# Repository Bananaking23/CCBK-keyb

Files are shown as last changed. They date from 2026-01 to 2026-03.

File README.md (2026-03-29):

# CCBK-keyb
I have decided to make this keyboard as I currently have a 68% keyboard and it feels bad not have f keys and home and delete, as I like to code and those keys are useful shortcuts. The switches I chose sound great and are relatively cheap. This project also improved my skills as I have only made a PCB ones (the hackpad). 

This is my berry cool 75% keyboard, it has a display, 80 keys, under-key lights, and a rotary encoder. It is powered by a rp2040 plus and uses an mcu23017 as gpio extender

# Photos

## almost full thing




for some reason i couldnt get all the keycaps on

## Scematic
### Main 


### Switch Matrix


### Led


## pcb

## Case


### Usb-c


### Plate


# BOM


### Link
https://1drv.ms/x/c/3f7de78506c0c654/IQBztQz0UetkR5LsrjEMn85vARuH-ncA3dCGhFmHGj_PK4U?e=rccWr9

#A fter completion

## Case



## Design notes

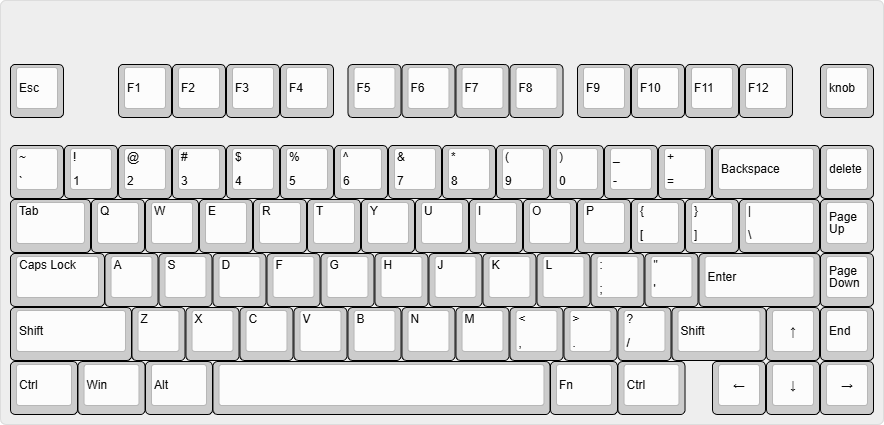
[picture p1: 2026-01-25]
KEYBOARD_DIY/keyboard-layout.png

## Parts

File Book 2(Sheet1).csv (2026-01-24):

name | description | price | amount | total price(GBP) | Total price(usd) | Running price | LINK
rp2040 plus | micrcontroller | 5.99 | 1 |  | 10.99 | 5.99 | https://www.waveshare.com/rp2040-plus.htm?sku=20290
creamy jade | switches | 16.31 | 1 | 16.31 | 22.1816 | 16.98 | https://s.click.aliexpress.com/e/_Ew0y6KC
kalih hotswap plugs | make kb hotwsap | 6.89 | 1 | 6.89 | 9.3704 | 39.1616 | https://s.click.aliexpress.com/e/_Eu0bNPO
MCP23017 | Port expander | 2.01 | 1 | 2.01 | 2.7336 | 48.532 | https://s.click.aliexpress.com/e/_EypYMqC
0.91 inch oled | shows info | 1.79 | 1 | 1.79 | 2.4344 | 51.2656 | https://a.aliexpress.com/_EuIBQWY
stabilizer | for long keys | 3.94 | 1 | 3.94 | 5.3584 | 53.7 | https://s.click.aliexpress.com/e/_ExPudE8
m3 heat inserts | screw things in | 2.46 | 1 | 2.46 | 3.3456 | 59.0584 | https://s.click.aliexpress.com/e/_EJB9bIc
rotary encoder | change things like volume | 0.79 | 1 | 0.79 | 1.0744 | 62.404 | https://s.click.aliexpress.com/e/_EuTjwLi
1n4148w diodes | stop ghosting | 1.25 | 1 | 1.25 | 1.7 | 63.4784 | https://s.click.aliexpress.com/e/_Ey54lbQ
step up converter | change 3.3v to 5v for leds | 0.72 | 1 | 0.72 | 0.9792 | 65.1784 | https://a.aliexpress.com/_ExfFVog
rubber feet | stop keyboard from slipping | 1.22 | 1 | 1.22 | 1.6592 | 66.1576 | https://s.click.aliexpress.com/e/_EHUOXNE
sk6812 mini | lights for keys | 4.69 | 1 | 4.69 | 6.3784 | 67.8168 | https://a.aliexpress.com/_EwElRLO
case | 3d printed-keep everything together | 0 | 1 | 0 | 0 | 67.8168
keycaps | for switches - already owned | 0 | 1 | 0 | 0 | 74.1952
pcb | connect all together | 25.87 | 1 | 0 | 25.87 | 74.1952 | https://jlcpcb.com
 |  |  |  |  |  | 100.0652 | With discounts: | $96

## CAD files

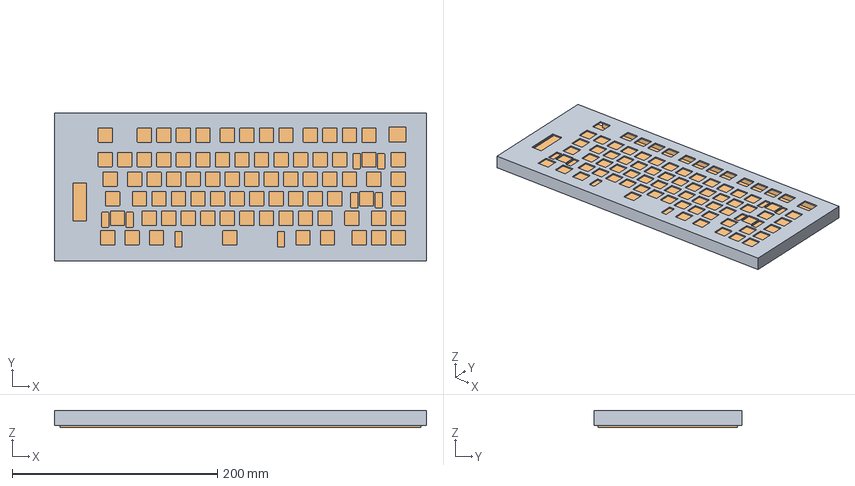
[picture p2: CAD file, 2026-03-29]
KEYBOARD_DIY/CAD/cad finished/complete.step
362.8 x 144.1 x 16.6 mm
PLATE
case

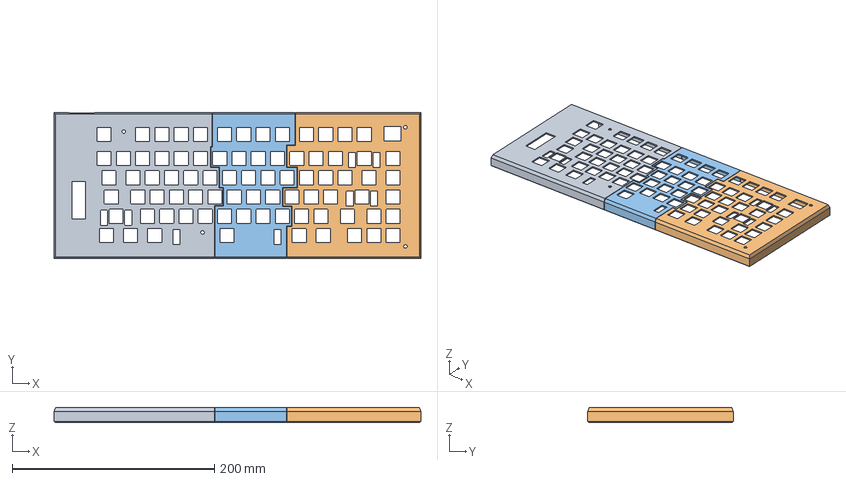
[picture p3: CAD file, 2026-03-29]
KEYBOARD_DIY/CAD/cad finished/PLATE.step
362.8 x 144.1 x 14.5 mm

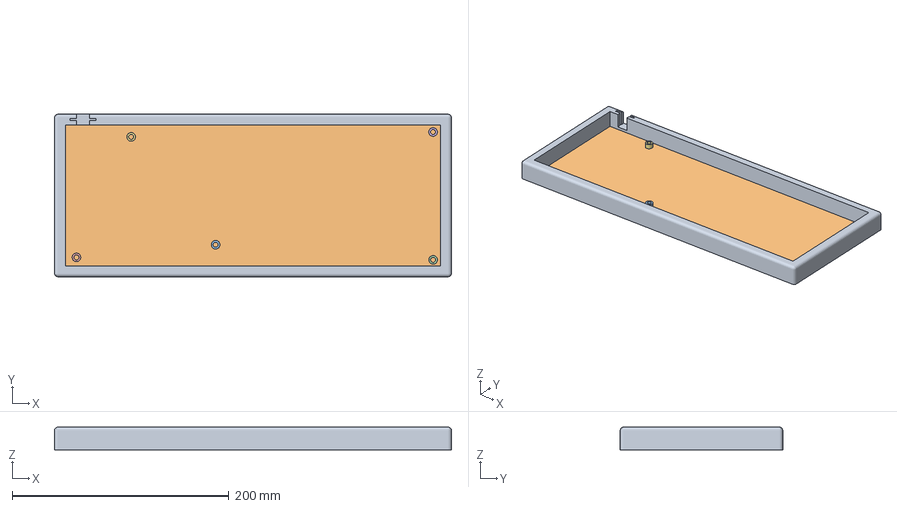
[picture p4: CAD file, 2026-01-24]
KEYBOARD_DIY/CAD/case.3mf
366.2 x 150.0 x 21.1 mm

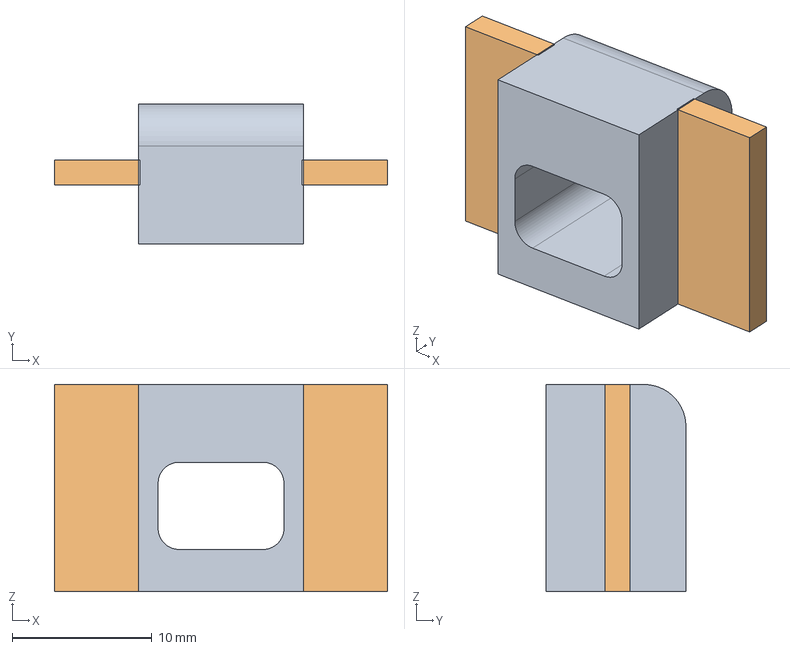
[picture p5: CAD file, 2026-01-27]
KEYBOARD_DIY/CAD/keyboard steps/USB.step
23.8 x 10.0 x 14.8 mm

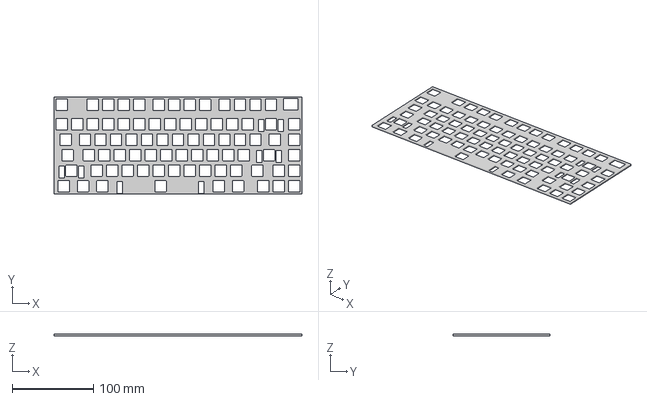
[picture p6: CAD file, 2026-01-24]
KEYBOARD_DIY/CAD/PLATE.3mf
304.8 x 119.1 x 2.00 mm

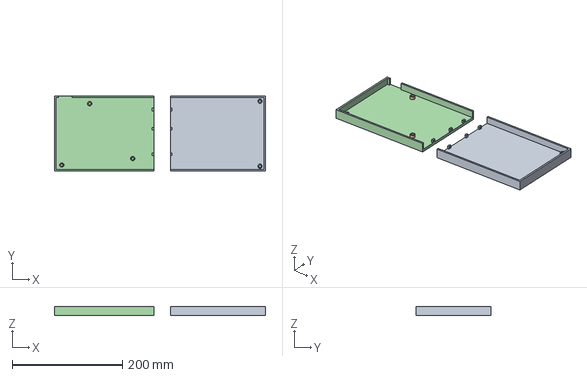
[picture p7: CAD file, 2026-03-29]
KEYBOARD_DIY/CAD/cad finished/case.step
382.2 x 136.0 x 16.1 mm

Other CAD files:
KEYBOARD_DIY/CAD/keyboard steps/case.step
KEYBOARD_DIY/CAD/USB.3mf
KEYBOARD_DIY/CAD/cad finished/PLATE.f3d
KEYBOARD_DIY/CAD/cad finished/case.f3d
KEYBOARD_DIY/CAD/cad finished/complete.f3z

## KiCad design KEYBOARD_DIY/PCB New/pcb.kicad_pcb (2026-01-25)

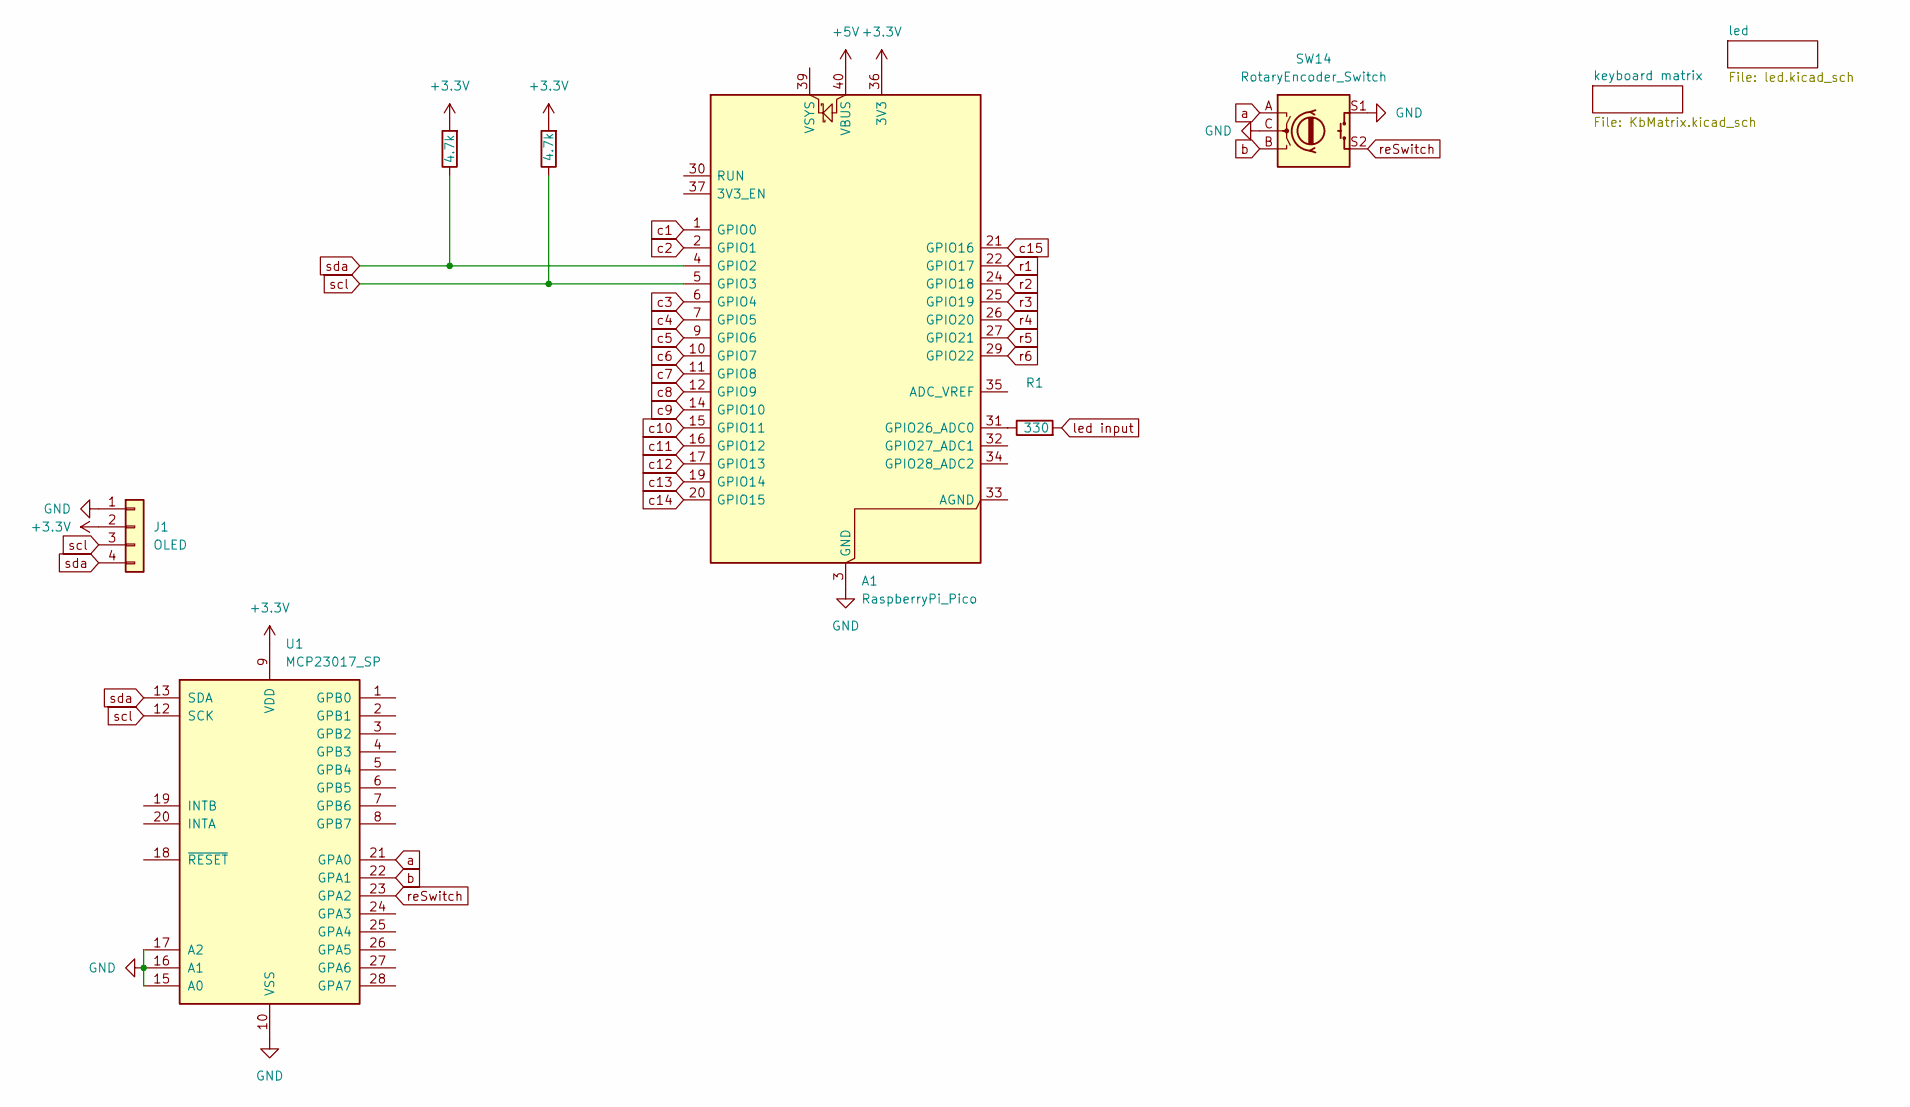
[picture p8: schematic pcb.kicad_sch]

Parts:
A1: RaspberryPi_Pico; RaspberryPi_Pico_Common_Unspecified
J1: OLED; SSD1306-0.91-OLED-4pin-128x32
R1: 330; R_Axial_DIN0207_L6.3mm_D2.5mm_P7.62mm_Horizontal
R2, R3: 4.7k; R_Axial_DIN0207_L6.3mm_D2.5mm_P7.62mm_Horizontal
SW14: RotaryEncoder_Switch; RotaryEncoder_Alps_EC11E-Switch_Vertical_H20mm
U1: MCP23017_SP; DIP-28_W7.62mm

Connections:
+3.3V: A1.36 (3V3), J1.2, R2.2, R3.2, U1.9 (VDD)
+5V: A1.40 (VBUS); also elsewhere on the board
GND: A1.3 (GND), A1.8 (GND), A1.13 (GND), A1.18 (GND), A1.23 (GND), A1.28 (GND), A1.38 (GND), J1.1, SW14.C, SW14.S1, U1.10 (VSS), U1.15 (A0), U1.16 (A1), U1.17 (A2); also elsewhere on the board
unnamed: A1.31 (GPIO26_ADC0), R1.1
a: SW14.A, U1.21 (GPA0)
b: SW14.B, U1.22 (GPA1)
c1: A1.1 (GPIO0); also elsewhere on the board
c2: A1.2 (GPIO1); also elsewhere on the board
c3: A1.6 (GPIO4); also elsewhere on the board
c4: A1.7 (GPIO5); also elsewhere on the board
c5: A1.9 (GPIO6); also elsewhere on the board
c6: A1.10 (GPIO7); also elsewhere on the board
c7: A1.11 (GPIO8); also elsewhere on the board
c8: A1.12 (GPIO9); also elsewhere on the board
c9: A1.14 (GPIO10); also elsewhere on the board
c10: A1.15 (GPIO11); also elsewhere on the board
c11: A1.16 (GPIO12); also elsewhere on the board
c12: A1.17 (GPIO13); also elsewhere on the board
c13: A1.19 (GPIO14); also elsewhere on the board
c14: A1.20 (GPIO15); also elsewhere on the board
c15: A1.21 (GPIO16); also elsewhere on the board
led input: R1.2; also elsewhere on the board
r1: A1.22 (GPIO17); also elsewhere on the board
r2: A1.24 (GPIO18); also elsewhere on the board
r3: A1.25 (GPIO19); also elsewhere on the board
r4: A1.26 (GPIO20); also elsewhere on the board
r5: A1.27 (GPIO21); also elsewhere on the board
r6: A1.29 (GPIO22); also elsewhere on the board
reSwitch: SW14.S2, U1.23 (GPA2)
scl: A1.5 (GPIO3), J1.3, R2.1, U1.12 (SCK)
sda: A1.4 (GPIO2), J1.4, R3.1, U1.13 (SDA)

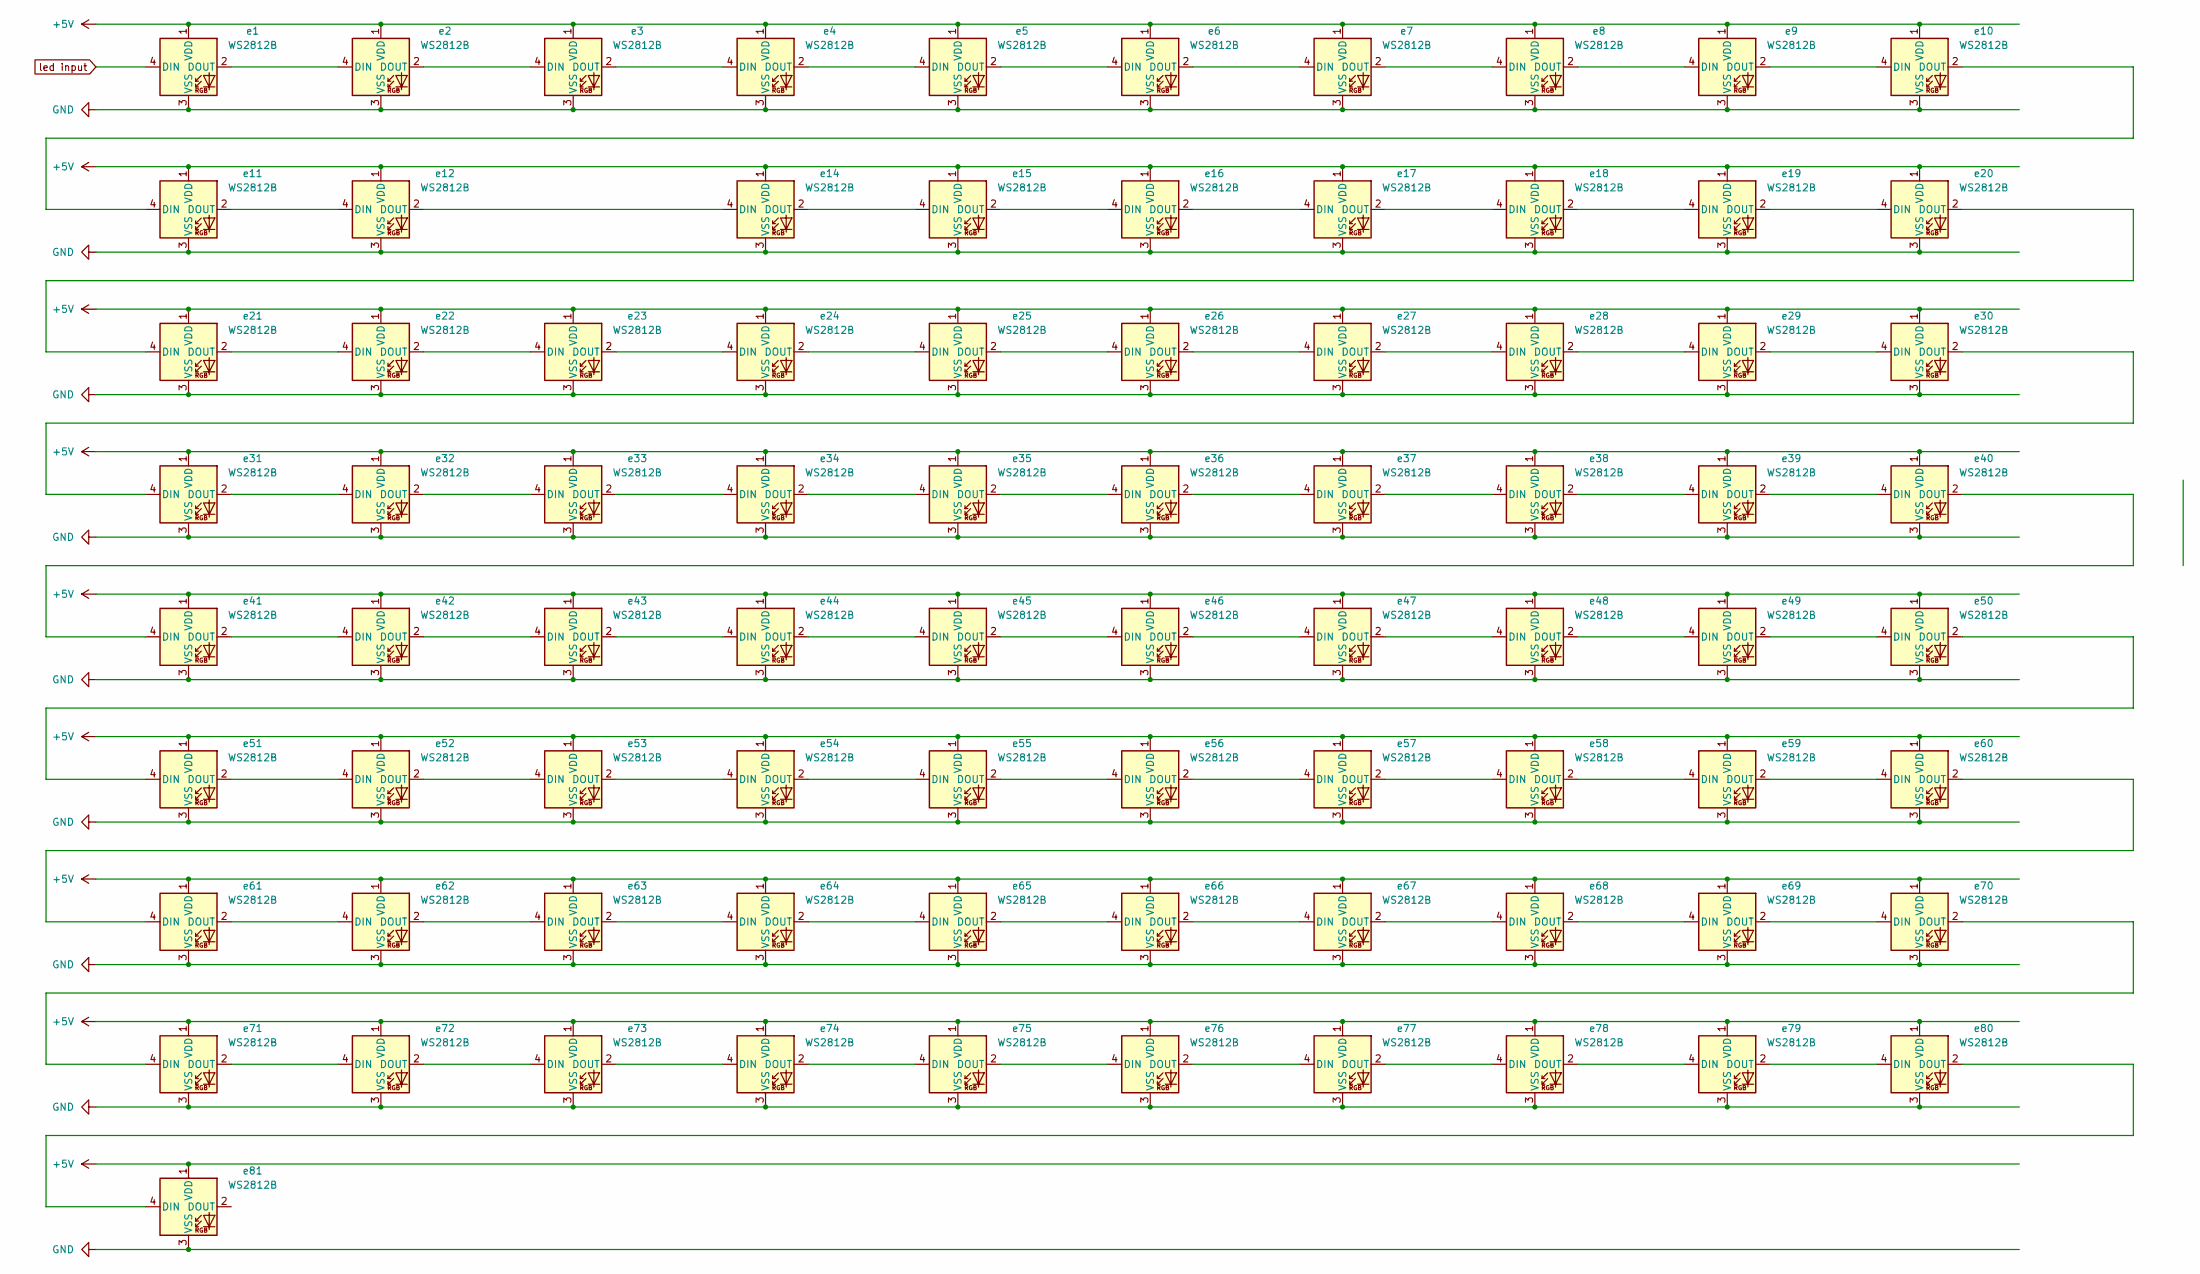
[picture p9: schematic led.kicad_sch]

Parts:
e1, e2, e3, e4, e5, e6, e7, e8, e9, e10, e11, e12, e14, e15, e16, e17, e18, e19, e20, e21, e22, e23, e24, e25, e26, e27, e28, e29, e30, e31, e32, e33, e34, e35, e36, e37, e38, e39, e40, e41, e42, e43, e44, e45, e46, e47, e48, e49, e50, e51, e52, e53, e54, e55, e56, e57, e58, e59, e60, e61, e62, e63, e64, e65, e66, e67, e68, e69, e70, e71, e72, e73, e74, e75, e76, e77, e78, e79, e80, e81: WS2812B; LED_SK6812MINI_PLCC4_3.5x3.5mm_P1.75mm

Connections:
+5V: e1.1 (VDD), e2.1 (VDD), e3.1 (VDD), e4.1 (VDD), e5.1 (VDD), e6.1 (VDD), e7.1 (VDD), e8.1 (VDD), e9.1 (VDD), e10.1 (VDD), e11.1 (VDD), e12.1 (VDD), e14.1 (VDD), e15.1 (VDD), e16.1 (VDD), e17.1 (VDD), e18.1 (VDD), e19.1 (VDD), e20.1 (VDD), e21.1 (VDD), e22.1 (VDD), e23.1 (VDD), e24.1 (VDD), e25.1 (VDD), e26.1 (VDD), e27.1 (VDD), e28.1 (VDD), e29.1 (VDD), e30.1 (VDD), e31.1 (VDD), e32.1 (VDD), e33.1 (VDD), e34.1 (VDD), e35.1 (VDD), e36.1 (VDD), e37.1 (VDD), e38.1 (VDD), e39.1 (VDD), e40.1 (VDD), e41.1 (VDD), e42.1 (VDD), e43.1 (VDD), e44.1 (VDD), e45.1 (VDD), e46.1 (VDD), e47.1 (VDD), e48.1 (VDD), e49.1 (VDD), e50.1 (VDD), e51.1 (VDD), e52.1 (VDD), e53.1 (VDD), e54.1 (VDD), e55.1 (VDD), e56.1 (VDD), e57.1 (VDD), e58.1 (VDD), e59.1 (VDD), e60.1 (VDD), e61.1 (VDD), e62.1 (VDD), e63.1 (VDD), e64.1 (VDD), e65.1 (VDD), e66.1 (VDD), e67.1 (VDD), e68.1 (VDD), e69.1 (VDD), e70.1 (VDD), e71.1 (VDD), e72.1 (VDD), e73.1 (VDD), e74.1 (VDD), e75.1 (VDD), e76.1 (VDD), e77.1 (VDD), e78.1 (VDD), e79.1 (VDD), e80.1 (VDD), e81.1 (VDD); also elsewhere on the board
GND: e1.3 (VSS), e2.3 (VSS), e3.3 (VSS), e4.3 (VSS), e5.3 (VSS), e6.3 (VSS), e7.3 (VSS), e8.3 (VSS), e9.3 (VSS), e10.3 (VSS), e11.3 (VSS), e12.3 (VSS), e14.3 (VSS), e15.3 (VSS), e16.3 (VSS), e17.3 (VSS), e18.3 (VSS), e19.3 (VSS), e20.3 (VSS), e21.3 (VSS), e22.3 (VSS), e23.3 (VSS), e24.3 (VSS), e25.3 (VSS), e26.3 (VSS), e27.3 (VSS), e28.3 (VSS), e29.3 (VSS), e30.3 (VSS), e31.3 (VSS), e32.3 (VSS), e33.3 (VSS), e34.3 (VSS), e35.3 (VSS), e36.3 (VSS), e37.3 (VSS), e38.3 (VSS), e39.3 (VSS), e40.3 (VSS), e41.3 (VSS), e42.3 (VSS), e43.3 (VSS), e44.3 (VSS), e45.3 (VSS), e46.3 (VSS), e47.3 (VSS), e48.3 (VSS), e49.3 (VSS), e50.3 (VSS), e51.3 (VSS), e52.3 (VSS), e53.3 (VSS), e54.3 (VSS), e55.3 (VSS), e56.3 (VSS), e57.3 (VSS), e58.3 (VSS), e59.3 (VSS), e60.3 (VSS), e61.3 (VSS), e62.3 (VSS), e63.3 (VSS), e64.3 (VSS), e65.3 (VSS), e66.3 (VSS), e67.3 (VSS), e68.3 (VSS), e69.3 (VSS), e70.3 (VSS), e71.3 (VSS), e72.3 (VSS), e73.3 (VSS), e74.3 (VSS), e75.3 (VSS), e76.3 (VSS), e77.3 (VSS), e78.3 (VSS), e79.3 (VSS), e80.3 (VSS), e81.3 (VSS); also elsewhere on the board
unnamed: e1.2 (DOUT), e2.4 (DIN)
unnamed: e2.2 (DOUT), e3.4 (DIN)
unnamed: e3.2 (DOUT), e4.4 (DIN)
unnamed: e4.2 (DOUT), e5.4 (DIN)
unnamed: e5.2 (DOUT), e6.4 (DIN)
unnamed: e6.2 (DOUT), e7.4 (DIN)
unnamed: e7.2 (DOUT), e8.4 (DIN)
unnamed: e8.2 (DOUT), e9.4 (DIN)
unnamed: e9.2 (DOUT), e10.4 (DIN)
unnamed: e10.2 (DOUT), e11.4 (DIN)
unnamed: e11.2 (DOUT), e12.4 (DIN)
unnamed: e12.2 (DOUT), e14.4 (DIN)
unnamed: e14.2 (DOUT), e15.4 (DIN)
unnamed: e15.2 (DOUT), e16.4 (DIN)
unnamed: e16.2 (DOUT), e17.4 (DIN)
unnamed: e17.2 (DOUT), e18.4 (DIN)
unnamed: e18.2 (DOUT), e19.4 (DIN)
unnamed: e19.2 (DOUT), e20.4 (DIN)
unnamed: e20.2 (DOUT), e21.4 (DIN)
unnamed: e21.2 (DOUT), e22.4 (DIN)
unnamed: e22.2 (DOUT), e23.4 (DIN)
unnamed: e23.2 (DOUT), e24.4 (DIN)
unnamed: e24.2 (DOUT), e25.4 (DIN)
unnamed: e25.2 (DOUT), e26.4 (DIN)
unnamed: e26.2 (DOUT), e27.4 (DIN)
unnamed: e27.2 (DOUT), e28.4 (DIN)
unnamed: e28.2 (DOUT), e29.4 (DIN)
unnamed: e29.2 (DOUT), e30.4 (DIN)
unnamed: e30.2 (DOUT), e31.4 (DIN)
unnamed: e31.2 (DOUT), e32.4 (DIN)
unnamed: e32.2 (DOUT), e33.4 (DIN)
unnamed: e33.2 (DOUT), e34.4 (DIN)
unnamed: e34.2 (DOUT), e35.4 (DIN)
unnamed: e35.2 (DOUT), e36.4 (DIN)
unnamed: e36.2 (DOUT), e37.4 (DIN)
unnamed: e37.2 (DOUT), e38.4 (DIN)
unnamed: e38.2 (DOUT), e39.4 (DIN)
unnamed: e39.2 (DOUT), e40.4 (DIN)
unnamed: e40.2 (DOUT), e41.4 (DIN)
unnamed: e41.2 (DOUT), e42.4 (DIN)
unnamed: e42.2 (DOUT), e43.4 (DIN)
unnamed: e43.2 (DOUT), e44.4 (DIN)
unnamed: e44.2 (DOUT), e45.4 (DIN)
unnamed: e45.2 (DOUT), e46.4 (DIN)
unnamed: e46.2 (DOUT), e47.4 (DIN)
unnamed: e47.2 (DOUT), e48.4 (DIN)
unnamed: e48.2 (DOUT), e49.4 (DIN)
unnamed: e49.2 (DOUT), e50.4 (DIN)
unnamed: e50.2 (DOUT), e51.4 (DIN)
unnamed: e51.2 (DOUT), e52.4 (DIN)
unnamed: e52.2 (DOUT), e53.4 (DIN)
unnamed: e53.2 (DOUT), e54.4 (DIN)
unnamed: e54.2 (DOUT), e55.4 (DIN)
unnamed: e55.2 (DOUT), e56.4 (DIN)
unnamed: e56.2 (DOUT), e57.4 (DIN)
unnamed: e57.2 (DOUT), e58.4 (DIN)
unnamed: e58.2 (DOUT), e59.4 (DIN)
unnamed: e59.2 (DOUT), e60.4 (DIN)
unnamed: e60.2 (DOUT), e61.4 (DIN)
unnamed: e61.2 (DOUT), e62.4 (DIN)
unnamed: e62.2 (DOUT), e63.4 (DIN)
unnamed: e63.2 (DOUT), e64.4 (DIN)
unnamed: e64.2 (DOUT), e65.4 (DIN)
unnamed: e65.2 (DOUT), e66.4 (DIN)
unnamed: e66.2 (DOUT), e67.4 (DIN)
unnamed: e67.2 (DOUT), e68.4 (DIN)
unnamed: e68.2 (DOUT), e69.4 (DIN)
unnamed: e69.2 (DOUT), e70.4 (DIN)
unnamed: e70.2 (DOUT), e71.4 (DIN)
unnamed: e71.2 (DOUT), e72.4 (DIN)
unnamed: e72.2 (DOUT), e73.4 (DIN)
unnamed: e73.2 (DOUT), e74.4 (DIN)
unnamed: e74.2 (DOUT), e75.4 (DIN)
unnamed: e75.2 (DOUT), e76.4 (DIN)
unnamed: e76.2 (DOUT), e77.4 (DIN)
unnamed: e77.2 (DOUT), e78.4 (DIN)
unnamed: e78.2 (DOUT), e79.4 (DIN)
unnamed: e79.2 (DOUT), e80.4 (DIN)
unnamed: e80.2 (DOUT), e81.4 (DIN)
led input: e1.4 (DIN); also elsewhere on the board

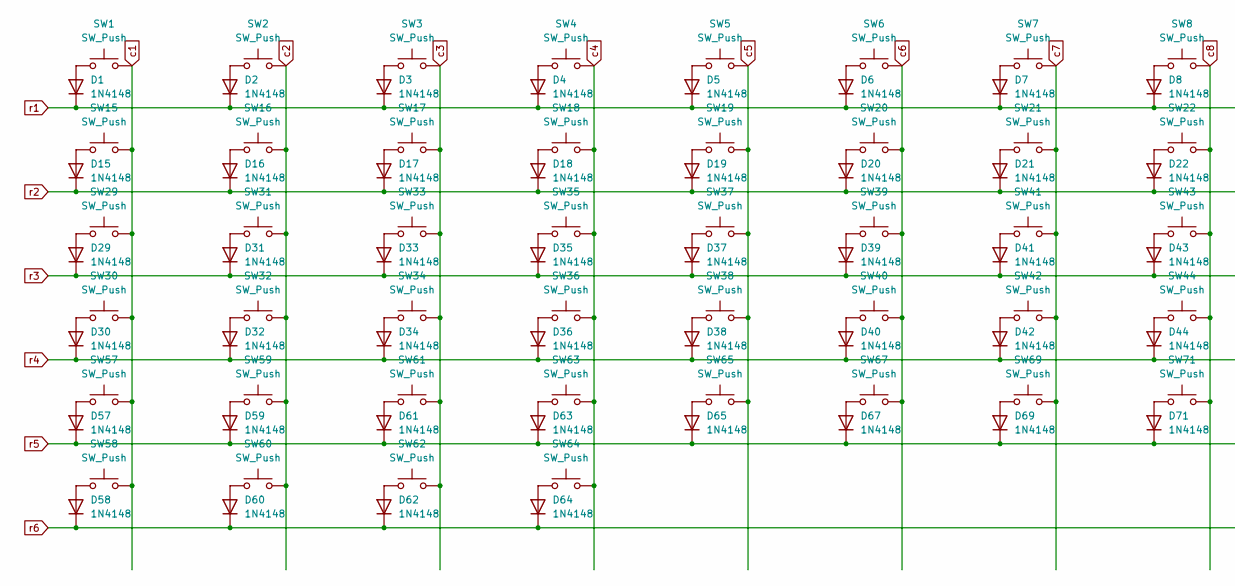
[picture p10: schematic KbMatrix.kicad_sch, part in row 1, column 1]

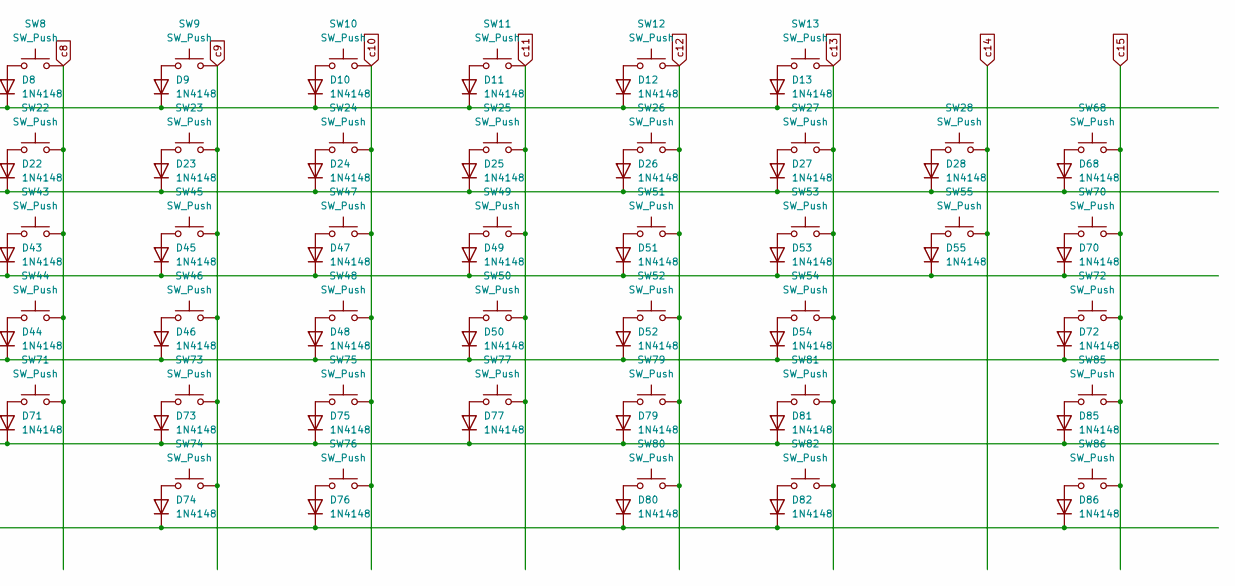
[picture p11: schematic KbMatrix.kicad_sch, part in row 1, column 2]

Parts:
D1, D2, D3, D4, D5, D6, D7, D8, D9, D10, D11, D12, D13, D15, D16, D17, D18, D19, D20, D21, D22, D23, D24, D25, D26, D27, D28, D29, D30, D31, D32, D33, D34, D35, D36, D37, D38, D39, D40, D41, D42, D43, D44, D45, D46, D47, D48, D49, D50, D51, D52, D53, D54, D55, D57, D58, D59, D60, D61, D62, D63, D64, D65, D67, D68, D69, D70, D71, D72, D73, D74, D75, D76, D77, D79, D80, D81, D82, D85, D86: 1N4148; D_SOD-123
SW1, SW2, SW3, SW4, SW5, SW6, SW7, SW8, SW9, SW10, SW11, SW12, SW13, SW15, SW16, SW17, SW18, SW19, SW20, SW21, SW22, SW23, SW24, SW25, SW26, SW27, SW31, SW32, SW33, SW34, SW35, SW36, SW37, SW38, SW39, SW40, SW41, SW42, SW43, SW44, SW45, SW46, SW47, SW48, SW49, SW50, SW51, SW52, SW53, SW59, SW61, SW63, SW65, SW67, SW68, SW69, SW70, SW71, SW72, SW73, SW75, SW77, SW80, SW81, SW82, SW85, SW86: SW_Push; SW_Hotswap_Kailh_MX_Plated_1.00u_EDITED
SW28: SW_Push; SW_Hotswap_Kailh_MX_Plated_2.00u
SW29, SW55: SW_Push; SW_Hotswap_Kailh_MX_Plated_1.50u
SW30, SW79: SW_Push; SW_Hotswap_Kailh_MX_Plated_1.75u
SW54, SW57: SW_Push; SW_Hotswap_Kailh_MX_Plated_2.25u
SW58, SW60, SW62, SW74, SW76: SW_Push; SW_Hotswap_Kailh_MX_Plated_1.25u
SW64: SW_Push; SW_Hotswap_Kailh_MX_Plated_6.25u

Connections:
unnamed: D1.2 (A), SW1.1
unnamed: D2.2 (A), SW2.1
unnamed: D3.2 (A), SW3.1
unnamed: D4.2 (A), SW4.1
unnamed: D5.2 (A), SW5.1
unnamed: D6.2 (A), SW6.1
unnamed: D7.2 (A), SW7.1
unnamed: D8.2 (A), SW8.1
unnamed: D9.2 (A), SW9.1
unnamed: D10.2 (A), SW10.1
unnamed: D11.2 (A), SW11.1
unnamed: D12.2 (A), SW12.1
unnamed: D13.2 (A), SW13.1
unnamed: D15.2 (A), SW15.1
unnamed: D16.2 (A), SW16.1
unnamed: D17.2 (A), SW17.1
unnamed: D18.2 (A), SW18.1
unnamed: D19.2 (A), SW19.1
unnamed: D20.2 (A), SW20.1
unnamed: D21.2 (A), SW21.1
unnamed: D22.2 (A), SW22.1
unnamed: D23.2 (A), SW23.1
unnamed: D24.2 (A), SW24.1
unnamed: D25.2 (A), SW25.1
unnamed: D26.2 (A), SW26.1
unnamed: D27.2 (A), SW27.1
unnamed: D28.2 (A), SW28.1
unnamed: D29.2 (A), SW29.1
unnamed: D30.2 (A), SW30.1
unnamed: D31.2 (A), SW31.1
unnamed: D32.2 (A), SW32.1
unnamed: D33.2 (A), SW33.1
unnamed: D34.2 (A), SW34.1
unnamed: D35.2 (A), SW35.1
unnamed: D36.2 (A), SW36.1
unnamed: D37.2 (A), SW37.1
unnamed: D38.2 (A), SW38.1
unnamed: D39.2 (A), SW39.1
unnamed: D40.2 (A), SW40.1
unnamed: D41.2 (A), SW41.1
unnamed: D42.2 (A), SW42.1
unnamed: D43.2 (A), SW43.1
unnamed: D44.2 (A), SW44.1
unnamed: D45.2 (A), SW45.1
unnamed: D46.2 (A), SW46.1
unnamed: D47.2 (A), SW47.1
unnamed: D48.2 (A), SW48.1
unnamed: D49.2 (A), SW49.1
unnamed: D50.2 (A), SW50.1
unnamed: D51.2 (A), SW51.1
unnamed: D52.2 (A), SW52.1
unnamed: D53.2 (A), SW53.1
unnamed: D54.2 (A), SW54.1
unnamed: D55.2 (A), SW55.1
unnamed: D57.2 (A), SW57.1
unnamed: D58.2 (A), SW58.1
unnamed: D59.2 (A), SW59.1
unnamed: D60.2 (A), SW60.1
unnamed: D61.2 (A), SW61.1
unnamed: D62.2 (A), SW62.1
unnamed: D63.2 (A), SW63.1
unnamed: D64.2 (A), SW64.1
unnamed: D65.2 (A), SW65.1
unnamed: D67.2 (A), SW67.1
unnamed: D68.2 (A), SW68.1
unnamed: D69.2 (A), SW69.1
unnamed: D70.2 (A), SW70.1
unnamed: D71.2 (A), SW71.1
unnamed: D72.2 (A), SW72.1
unnamed: D73.2 (A), SW73.1
unnamed: D74.2 (A), SW74.1
unnamed: D75.2 (A), SW75.1
unnamed: D76.2 (A), SW76.1
unnamed: D77.2 (A), SW77.1
unnamed: D79.2 (A), SW79.1
unnamed: D80.2 (A), SW80.1
unnamed: D81.2 (A), SW81.1
unnamed: D82.2 (A), SW82.1
unnamed: D85.2 (A), SW85.1
unnamed: D86.2 (A), SW86.1
c1: SW1.2, SW15.2, SW29.2, SW30.2, SW57.2, SW58.2; also elsewhere on the board
c2: SW2.2, SW16.2, SW31.2, SW32.2, SW59.2, SW60.2; also elsewhere on the board
c3: SW3.2, SW17.2, SW33.2, SW34.2, SW61.2, SW62.2; also elsewhere on the board
c4: SW4.2, SW18.2, SW35.2, SW36.2, SW63.2, SW64.2; also elsewhere on the board
c5: SW5.2, SW19.2, SW37.2, SW38.2, SW65.2; also elsewhere on the board
c6: SW6.2, SW20.2, SW39.2, SW40.2, SW67.2; also elsewhere on the board
c7: SW7.2, SW21.2, SW41.2, SW42.2, SW69.2; also elsewhere on the board
c8: SW8.2, SW22.2, SW43.2, SW44.2, SW71.2; also elsewhere on the board
c9: SW9.2, SW23.2, SW45.2, SW46.2, SW73.2, SW74.2; also elsewhere on the board
c10: SW10.2, SW24.2, SW47.2, SW48.2, SW75.2, SW76.2; also elsewhere on the board
c11: SW11.2, SW25.2, SW49.2, SW50.2, SW77.2; also elsewhere on the board
c12: SW12.2, SW26.2, SW51.2, SW52.2, SW79.2, SW80.2; also elsewhere on the board
c13: SW13.2, SW27.2, SW53.2, SW54.2, SW81.2, SW82.2; also elsewhere on the board
c14: SW28.2, SW55.2; also elsewhere on the board
c15: SW68.2, SW70.2, SW72.2, SW85.2, SW86.2; also elsewhere on the board
r1: D1.1 (K), D2.1 (K), D3.1 (K), D4.1 (K), D5.1 (K), D6.1 (K), D7.1 (K), D8.1 (K), D9.1 (K), D10.1 (K), D11.1 (K), D12.1 (K), D13.1 (K); also elsewhere on the board
r2: D15.1 (K), D16.1 (K), D17.1 (K), D18.1 (K), D19.1 (K), D20.1 (K), D21.1 (K), D22.1 (K), D23.1 (K), D24.1 (K), D25.1 (K), D26.1 (K), D27.1 (K), D28.1 (K), D68.1 (K); also elsewhere on the board
r3: D29.1 (K), D31.1 (K), D33.1 (K), D35.1 (K), D37.1 (K), D39.1 (K), D41.1 (K), D43.1 (K), D45.1 (K), D47.1 (K), D49.1 (K), D51.1 (K), D53.1 (K), D55.1 (K), D70.1 (K); also elsewhere on the board
r4: D30.1 (K), D32.1 (K), D34.1 (K), D36.1 (K), D38.1 (K), D40.1 (K), D42.1 (K), D44.1 (K), D46.1 (K), D48.1 (K), D50.1 (K), D52.1 (K), D54.1 (K), D72.1 (K); also elsewhere on the board
r5: D57.1 (K), D59.1 (K), D61.1 (K), D63.1 (K), D65.1 (K), D67.1 (K), D69.1 (K), D71.1 (K), D73.1 (K), D75.1 (K), D77.1 (K), D79.1 (K), D81.1 (K), D85.1 (K); also elsewhere on the board
r6: D58.1 (K), D60.1 (K), D62.1 (K), D64.1 (K), D74.1 (K), D76.1 (K), D80.1 (K), D82.1 (K), D86.1 (K); also elsewhere on the board

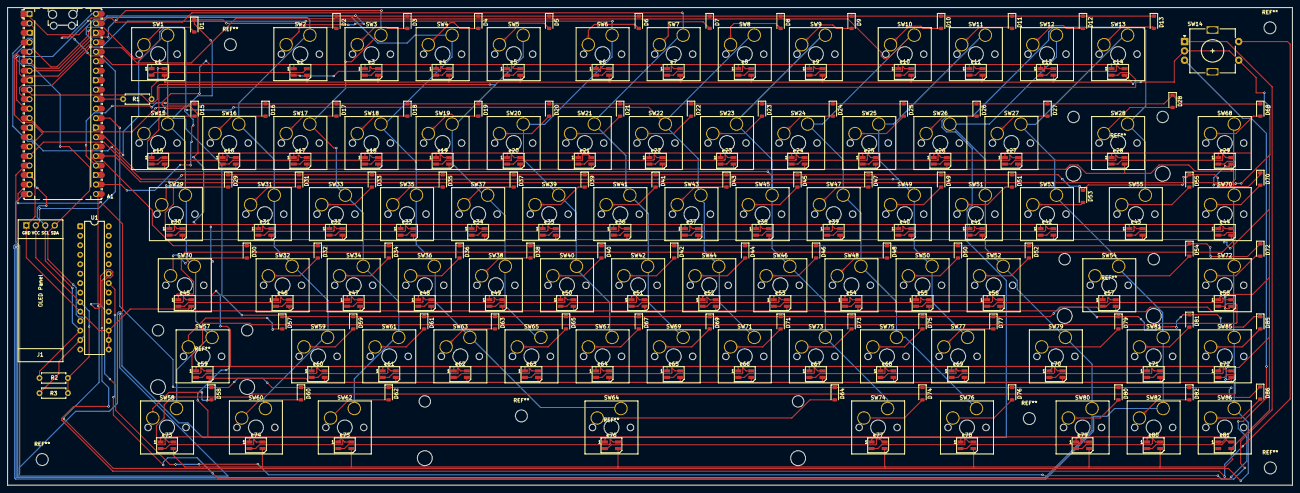
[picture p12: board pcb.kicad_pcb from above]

Board: 2 copper layers, 344.2 x 128.0 mm, 247 parts (0 on the bottom side), 190 nets.

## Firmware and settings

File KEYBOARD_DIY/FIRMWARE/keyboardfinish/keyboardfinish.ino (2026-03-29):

#include "Adafruit_TinyUSB.h"

// ================= USB HID =================
Adafruit_USBD_HID usb_hid;

uint8_t const desc_hid_report[] = {
  TUD_HID_REPORT_DESC_KEYBOARD()
};

// ================= PINS =================
const int ROW_PINS[6]  = {17, 18, 19, 20, 21, 22};
const int COL_PINS[15] = {
  0, 1, 4, 5, 6, 7, 8,
  9, 10, 11, 12, 13,
  16, 15, 14
};

// ================= CONFIG =================
#define NUM_ROWS 6
#define NUM_COLS 15
#define NUM_LAYERS 2

#define KT_KB 0
#define KT_FN 1
#define KT_NONE 2

struct Key { uint8_t type; uint8_t code; };

// ================= KEYMAP =================
Key keyMap[NUM_LAYERS][NUM_ROWS][NUM_COLS] = {

  // ===== BASE =====
  {
    {
      {KT_KB,HID_KEY_ESCAPE},{KT_KB,HID_KEY_F1},{KT_KB,HID_KEY_F2},{KT_KB,HID_KEY_F3},
      {KT_KB,HID_KEY_F4},{KT_KB,HID_KEY_F5},{KT_KB,HID_KEY_F6},{KT_KB,HID_KEY_F7},
      {KT_KB,HID_KEY_F8},{KT_KB,HID_KEY_F9},{KT_KB,HID_KEY_F10},{KT_KB,HID_KEY_F11},
      {KT_KB,HID_KEY_F12},{KT_NONE,0},{KT_NONE,0}
    },

    {
      {KT_KB,HID_KEY_GRAVE},{KT_KB,HID_KEY_1},{KT_KB,HID_KEY_2},{KT_KB,HID_KEY_3},
      {KT_KB,HID_KEY_4},{KT_KB,HID_KEY_5},{KT_KB,HID_KEY_6},{KT_KB,HID_KEY_7},
      {KT_KB,HID_KEY_8},{KT_KB,HID_KEY_9},{KT_KB,HID_KEY_0},{KT_KB,HID_KEY_MINUS},
      {KT_KB,HID_KEY_EQUAL},{KT_KB,HID_KEY_BACKSPACE},{KT_KB,HID_KEY_DELETE}
    },

    {
      {KT_KB,HID_KEY_TAB},{KT_KB,HID_KEY_Q},{KT_KB,HID_KEY_W},{KT_KB,HID_KEY_E},
      {KT_KB,HID_KEY_R},{KT_KB,HID_KEY_T},{KT_KB,HID_KEY_Y},{KT_KB,HID_KEY_U},
      {KT_KB,HID_KEY_I},{KT_KB,HID_KEY_O},{KT_KB,HID_KEY_P},{KT_KB,HID_KEY_BRACKET_LEFT},
      {KT_KB,HID_KEY_BRACKET_RIGHT},{KT_KB,HID_KEY_BACKSLASH},{KT_KB,HID_KEY_PAGE_UP}
    },

    {
      {KT_KB,HID_KEY_CAPS_LOCK},{KT_KB,HID_KEY_A},{KT_KB,HID_KEY_S},{KT_KB,HID_KEY_D},
      {KT_KB,HID_KEY_F},{KT_KB,HID_KEY_G},{KT_KB,HID_KEY_H},{KT_KB,HID_KEY_J},
      {KT_KB,HID_KEY_K},{KT_KB,HID_KEY_L},{KT_KB,HID_KEY_SEMICOLON},{KT_KB,HID_KEY_APOSTROPHE},
      {KT_KB,HID_KEY_ENTER},{KT_KB,HID_KEY_PAGE_DOWN},{KT_NONE,0}
    },

    {
      {KT_KB,HID_KEY_SHIFT_LEFT},{KT_KB,HID_KEY_Z},{KT_KB,HID_KEY_X},{KT_KB,HID_KEY_C},
      {KT_KB,HID_KEY_V},{KT_KB,HID_KEY_B},{KT_KB,HID_KEY_N},{KT_KB,HID_KEY_M},
      {KT_KB,HID_KEY_COMMA},{KT_KB,HID_KEY_PERIOD},{KT_KB,HID_KEY_SLASH},{KT_KB,HID_KEY_SHIFT_RIGHT},
      {KT_KB,HID_KEY_ARROW_UP},{KT_KB,HID_KEY_END},{KT_NONE,0}
    },

    {
      {KT_KB,HID_KEY_CONTROL_LEFT},
      {KT_KB,HID_KEY_GUI_LEFT},
      {KT_KB,HID_KEY_ALT_LEFT},
      {KT_KB,HID_KEY_SPACE},

      {KT_NONE,0},{KT_NONE,0},{KT_NONE,0},

      {KT_FN,0},

      {KT_KB,HID_KEY_CONTROL_RIGHT},

      {KT_NONE,0},

      {KT_KB,HID_KEY_ARROW_LEFT},
      {KT_KB,HID_KEY_ARROW_DOWN},
      {KT_KB,HID_KEY_ARROW_RIGHT},

      {KT_NONE,0},{KT_NONE,0}
    }
  },

  // ===== FN =====
  {
    {
      {KT_KB,HID_KEY_ESCAPE},{KT_KB,HID_KEY_F1},{KT_KB,HID_KEY_F2},{KT_KB,HID_KEY_F3},
      {KT_KB,HID_KEY_F4},{KT_KB,HID_KEY_F5},{KT_KB,HID_KEY_F6},{KT_KB,HID_KEY_F7},
      {KT_KB,HID_KEY_F8},{KT_KB,HID_KEY_F9},{KT_KB,HID_KEY_F10},{KT_KB,HID_KEY_F11},
      {KT_KB,HID_KEY_F12},{KT_NONE,0},{KT_NONE,0}
    },

    {
      {KT_KB,HID_KEY_GRAVE},{KT_KB,HID_KEY_1},{KT_KB,HID_KEY_2},{KT_KB,HID_KEY_3},
      {KT_KB,HID_KEY_4},{KT_KB,HID_KEY_5},{KT_KB,HID_KEY_6},{KT_KB,HID_KEY_7},
      {KT_KB,HID_KEY_8},{KT_KB,HID_KEY_9},{KT_KB,HID_KEY_0},{KT_KB,HID_KEY_MINUS},
      {KT_KB,HID_KEY_EQUAL},{KT_KB,HID_KEY_BACKSPACE},{KT_KB,HID_KEY_DELETE}
    },

    {
      {KT_KB,HID_KEY_TAB},{KT_KB,HID_KEY_Q},{KT_KB,HID_KEY_W},{KT_KB,HID_KEY_E},
      {KT_KB,HID_KEY_R},{KT_KB,HID_KEY_T},{KT_KB,HID_KEY_Y},{KT_KB,HID_KEY_U},
      {KT_KB,HID_KEY_I},{KT_KB,HID_KEY_O},{KT_KB,HID_KEY_P},{KT_KB,HID_KEY_BRACKET_LEFT},
      {KT_KB,HID_KEY_BRACKET_RIGHT},{KT_KB,HID_KEY_BACKSLASH},{KT_KB,HID_KEY_HOME}
    },

    {
      {KT_KB,HID_KEY_CAPS_LOCK},{KT_KB,HID_KEY_A},{KT_KB,HID_KEY_S},{KT_KB,HID_KEY_D},
      {KT_KB,HID_KEY_F},{KT_KB,HID_KEY_G},{KT_KB,HID_KEY_H},{KT_KB,HID_KEY_J},
      {KT_KB,HID_KEY_K},{KT_KB,HID_KEY_L},{KT_KB,HID_KEY_SEMICOLON},{KT_KB,HID_KEY_APOSTROPHE},
      {KT_KB,HID_KEY_ENTER},{KT_KB,HID_KEY_END},{KT_NONE,0}
    },

    {
      {KT_KB,HID_KEY_SHIFT_LEFT},{KT_KB,HID_KEY_Z},{KT_KB,HID_KEY_X},{KT_KB,HID_KEY_C},
      {KT_KB,HID_KEY_V},{KT_KB,HID_KEY_B},{KT_KB,HID_KEY_N},{KT_KB,HID_KEY_M},
      {KT_KB,HID_KEY_COMMA},{KT_KB,HID_KEY_PERIOD},{KT_KB,HID_KEY_SLASH},{KT_KB,HID_KEY_SHIFT_RIGHT},
      {KT_KB,HID_KEY_PAGE_UP},{KT_KB,HID_KEY_END},{KT_NONE,0}
    },

    {
      {KT_KB,HID_KEY_CONTROL_LEFT},
      {KT_KB,HID_KEY_GUI_LEFT},
      {KT_KB,HID_KEY_ALT_LEFT},
      {KT_KB,HID_KEY_SPACE},

      {KT_NONE,0},{KT_NONE,0},{KT_NONE,0},

      {KT_FN,0},

      {KT_KB,HID_KEY_CONTROL_RIGHT},

      {KT_NONE,0},

      {KT_KB,HID_KEY_HOME},
      {KT_KB,HID_KEY_PAGE_DOWN},
      {KT_KB,HID_KEY_END},

      {KT_NONE,0},{KT_NONE,0}
    }
  }
};

// ================= STATE =================
bool keyStates[NUM_ROWS * NUM_COLS] = {false};
unsigned long lastPress[NUM_ROWS * NUM_COLS] = {0};
const unsigned long DEBOUNCE_MS = 10;

int currentLayer = 0;

// ================= SETUP =================
void setup() {
  usb_hid.setReportDescriptor(desc_hid_report, sizeof(desc_hid_report));
  usb_hid.begin();

  for (int r = 0; r < NUM_ROWS; r++) {
    pinMode(ROW_PINS[r], OUTPUT);
    digitalWrite(ROW_PINS[r], HIGH);
  }

  for (int c = 0; c < NUM_COLS; c++) {
    pinMode(COL_PINS[c], INPUT_PULLUP);
  }
}

// ================= LOOP =================
void loop() {
  scanMatrix();
}

// ================= MATRIX =================
void scanMatrix() {
  unsigned long now = millis();

  for (int r = 0; r < NUM_ROWS; r++) {
    digitalWrite(ROW_PINS[r], LOW);
    delayMicroseconds(5);

    for (int c = 0; c < NUM_COLS; c++) {
      int idx = r * NUM_COLS + c;
      bool pressed = (digitalRead(COL_PINS[c]) == LOW);

      if (pressed && !keyStates[idx] && (now - lastPress[idx] > DEBOUNCE_MS)) {
        keyStates[idx] = true;
        lastPress[idx] = now;
        pressKey(r, c);
      }
      else if (!pressed && keyStates[idx]) {
        keyStates[idx] = false;
        releaseKey(r, c);
      }
    }

    digitalWrite(ROW_PINS[r], HIGH);
  }
}

// ================= HID =================
uint8_t keyReport[6] = {0};

void sendReport() {
  usb_hid.keyboardReport(0, 0, keyReport);
}

void pressKey(int r, int c) {
  Key k = keyMap[currentLayer][r][c];

  if (k.type == KT_FN) {
    currentLayer = 1;
    return;
  }

  if (k.type == KT_NONE) return;

  for (int i = 0; i < 6; i++) {
    if (keyReport[i] == 0) {
      keyReport[i] = k.code;
      break;
    }
  }

  sendReport();
}

void releaseKey(int r, int c) {
  Key k = keyMap[currentLayer][r][c];

  if (k.type == KT_FN) {
    currentLayer = 0;
    return;
  }

  if (k.type == KT_NONE) return;
  for (int i = 0; i < 6; i++) {
    if (keyReport[i] == k.code) {
      keyReport[i] = 0;
    }
  }
  
  sendReport();
}

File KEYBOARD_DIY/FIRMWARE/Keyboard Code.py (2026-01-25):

from kmk.kmk_keyboard import KMKKeyboard
from kmk.keys import KC
from kmk.scanners import DiodeOrientation, DiodeScanner
from kmk.extensions.rgb import RGB
from kmk.modules.oled import OLED
import board

keyboard = KMKKeyboard()

# ------------------------
# MATRIX CONFIGURATION
# ------------------------
rows = [board.GP17, board.GP18, board.GP19, board.GP20, board.GP21, board.GP22]
cols = [
    board.GP0, board.GP1, board.GP4, board.GP5, board.GP6, board.GP7,
    board.GP8, board.GP9, board.GP10, board.GP11, board.GP12, board.GP13,
    board.GP14, board.GP15, board.GP16
]

scanner = DiodeScanner(rows=rows, cols=cols, diode_orientation=DiodeOrientation.COL2ROW)
keyboard.scanner = scanner

# ------------------------
# RGB CONFIGURATION
# ------------------------
keyboard.rgb = RGB(
    pixel_pin=board.GP26,    # SK6812 data pin
    num_pixels=80,           # Total number of LEDs
    val_limit=128            # Optional: lower brightness for power
)

keyboard.rgb.mode = 1  # simple breathing effect

# ------------------------
# OLED CONFIGURATION
# ------------------------
oled_ext = OLED(
    width=128,
    height=32,
    i2c_bus=0,
    i2c_sda=board.GP2,
    i2c_scl=board.GP3
)
keyboard.modules.append(oled_ext)

# ------------------------
# FULL KEYMAP
# ------------------------
keyboard.keymap = [
    [KC.ESC, KC.F1, KC.F2, KC.F3, KC.F4, KC.F5, KC.F6, KC.F7, KC.F8, KC.F9, KC.F10, KC.F11, KC.F12, KC.PRNT, KC.SCRL],
    [KC.GRAVE, KC.1, KC.2, KC.3, KC.4, KC.5, KC.6, KC.7, KC.8, KC.9, KC.0, KC.MINS, KC.EQL, KC.BSPC, KC.INS],
    [KC.TAB, KC.Q, KC.W, KC.E, KC.R, KC.T, KC.Y, KC.U, KC.I, KC.O, KC.P, KC.LBRC, KC.RBRC, KC.BSLS, KC.DEL],
    [KC.CAPS, KC.A, KC.S, KC.D, KC.F, KC.G, KC.H, KC.J, KC.K, KC.L, KC.SCLN, KC.QUOT, KC.ENTER, KC.HOME, KC.END],
    [KC.LSHIFT, KC.Z, KC.X, KC.C, KC.V, KC.B, KC.N, KC.M, KC.COMM, KC.DOT, KC.SLSH, KC.RSHIFT, KC.UP, KC.PGUP, KC.PGDN],
    [KC.LCTRL, KC.LGUI, KC.LALT, KC.SPC, KC.RALT, KC.RGUI, KC.MENU, KC.RCTRL, KC.LEFT, KC.DOWN, KC.RIGHT, KC.NO, KC.NO, KC.NO, KC.NO]
]

if __name__ == "__main__":
    keyboard.go()

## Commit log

2026-01-24 Enhance keyboard description in README
    Updated description to include rotary encoder and gpio extender.
2026-01-24 Update BOM image and link in README
    Updated BOM image and link in README.
2026-01-25 added all
    [KbMatrix.kicad_sch, PLATE.3mf, USB.3mf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]
2026-01-25 Update images in README.md for schematic and PCB
2026-01-25 added all fils
    [KbMatrix.kicad_sch, PLATE.3mf, USB.3mf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]
2026-02-15 Replace images in README.md and update PCB section
2026-02-15 Revise case section and add new images
    Updated images and sections in the README to reflect changes in the case design.
